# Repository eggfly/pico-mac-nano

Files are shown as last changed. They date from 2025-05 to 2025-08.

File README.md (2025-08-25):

# pico-mac-nano

pico-mac-nano
pico-mac-nanobig brotherinside

v0.3 20 May 2025

Fork of https://github.com/evansm7/pico-mac v0.21

The purpose of this fork is the creation of a miniature functioning Macintosh running pico-mac on a [Waveshare Pico Zero](https://www.waveshare.com/wiki/RP2040-Zero) (or pin/function compatible RP2040 MCU) by adding support for output to a small TFT LCD panel. 

This involved the following steps:
   * Selecting and testing the smallest suitably high resolution display I could locate at
     a reasonable price.
   * Working backwards from the LCD image size to calculate scale of the Macintosh model.
   * Designing the internal layout of the Macintosh to accomodate all components.
   * 3D modelling the Macintosh case in two halves with internal supports for components
   * Designing a PCB to connect all components.
   * Updating the pico-mac source code to ...
   	 - configure the LCD via SPI interface shared with SD card module
   	 - output suitable 480x342 pixel frame buffer data for the LCD
   	 - use the Pico Zero's built in Neo-pixel RGB LED
   	 - output out of phase 600Hz square waves on two GPIOs for 1s at startup to simulate
   	  the Macintosh startup beep

The finished Macintosh is just 62mm high but houses a 2.0" TFT LCD panel, rp2040 Pico Zero MCU, micro-SD card reader and the custom PCB.

For more details on the journey and design decisions, see the [pico-mac-nano project page](https://blog.1bitrainbow.com/pico-mac-nano/).

The firmware directory contains an example, pre-built .uf2 rp2040 firmware file for the Pico Zero. This version is built with the standard 128K ram.

The PCB directory contains all gerber, drill hole, position and BOM files for the most recent revision of the PCB.

Data sheets for the TFT module and the controller are in the data_sheets directory.

The 3D_model directory contains the .stl files for the four components of the Macintosh 128K case; front housing, rear housing, switch blank (blocks the switch apperture intended for the [battery power module](https://www.1bitrainbow.com/parts-store.php?cPath=972_973_P4470)) and reset/boot select button actuator.

All parts used in pico-mac-nano can be ordered on [1bitrainbow.com](https://www.1bitrainbow.com/parts-store.php?cPath=972_973). This includes the 3D printed case, the fully assembled custom PCB and the Pico Zero (pre-flashed with the latest pico-mac-nano firmware). You can even order a fully assembled pico-mac-nano or the collectors edition so you can be as hands-on or hands-off as you want.

## Hardware Notes

The pico code, PCB and Macintosh case are all designed for the 2.0" 480x640px DX7 D200N2409V0 LCD panel. This uses the ST7701S controller, is configured via SPI and receives image data in RGB565 (16-bit colour). This LCD is natively portrait and the ST7701S controller does not offer image rotation in hardware so I am displaying a 480x342 image across the upper half of the LCD panel. See the [pico-mac-nano project page](https://blog.1bitrainbow.com/pico-mac-nano/) for more details of how I got to this decision.

The case and internal layout is designed to allow the Pico Zero and SD module to be connected via 2.54mm header sockets rather than being soldered. Due to the small size of the PCB, I chose not to include sockets for the unused Pico Zero pins. Not having these unnecessary through-hole pins allowed routing of traces more efficiently. Consequently, the Pico Zero connects to the PCB via a 9-pin (J3), a 2-pin (J4), and a 4-pin (J6) socket.

The PCB includes the capacitors (C1 & C2) recommended by evansm7 across the micro-SD card module power rails.

The Pico 5V (VCC) is used to power the TFT backlight via a resistor (R1) which maintains the correct forward voltage specified by the TFT data sheet.

The 40-pin, vertical FFC socket (J1) is used to connect the TFT LCD panel. Note that for some reason, the LCD flex cable has its 'pin' numbers labelled in the reverse order to the FCC socket. This is why the PCB indicates where the LCD flex pin 1 should be.

Labelled test pads are provided on the PCB for all data signals.

Provision for battery power is provided on the PCB in the form of +5v and Ground header pins. This 5v input passes through an on-board Schottky diode (D1) to protect against pico-mac-nano being connected to a USB host and receiving 5V via USB while using battery power.
The optional battery power module which uses a 3v lithium C2 battery, 5v boost regulator and micro switch, is available now on [1bitrainbow.com](https://www.1bitrainbow.com/parts-store.php?cPath=972_973_P4470).

All components should be mounted on the underside of the PCB with the exception of the 2-pin 2.54mm male header (right-angle if using the [1-bit rainbow battery power module](https://www.1bitrainbow.com/parts-store.php?cPath=972_973_P4470)) for 5v battery power, and the 2-pin 2.54mm female header for Audio (Beep). These should be mounted on the top to allow connection of a power source and/or speaker.

pcb bottom
pcb top side

For reference, here are the pin assignments I have used for the Pico Zero.

|**Pin**|Ref|**Function**|
| --- | --- | --- |
|1		|5V			|VCC (TFT Backlight)|
|2		|GND		|Ground|
|3		|3V3		|VDD|
|4		|GPIO 29	|H-Sync|
|5		|GPIO 28	|Pix Clk|
|6		|GPIO 27	|V-Sync|
|7		|GPIO 26	|Vid Data|
|8		|GPIO 15	|TFT Reset|
|9		|GPIO 14	|TFT SPI CS|
|10		|GPIO 13	|Audio +|
|11		|GPIO 12	|Audio -|
|12		|GPIO 11	|N/C|
|13		|GPIO 10	|N/C|
|14		|GPIO 9		|N/C|
|15		|GPIO 8		|N/C|
|16		|GPIO 7		|N/C|
|17		|GPIO 6		|N/C|
|18		|GPIO 5		|SD SPI CS|
|19		|GPIO 4		|SPI MISO (shared)|
|20		|GPIO 3		|SPI MOSI (shared)|
|21		|GPIO 2		|SPI Clk (shared)|
|22		|GPIO 1		|N/C|
|23		|GPIO 0		|N/C|

The Audio + and Audio - pins output a 600Hz square wave for 1 second at the start of the initialisation code to give an approximate rendition of the original Macintosh startup beep. Audio - is just the inverse of (180 deg out of sync with) Audio +. By connecting a speaker between this pair of outputs, we get a 6.6v differential signal which gave an acceptable volume without the need for any amplification. When the speaker was just connected between one output and ground, the volume was too low to be of use (In case you're worrying, both pins are set low after the beep so the Pico is not left with a high GPIO shorting to ground through the speaker).
Audio + and Audio - are presented on their own header pins on the PCB to allow a speaker to be easily connected.
Using a suitable inductor (the value will depend on the impedance of the speaker you are using) in series with the speaker, or a capacitor across the speaker, should filter out some of the higher frequencies so the beep is less buzzy.

As with the pico-mac project, pico-mac-nano is a personal hobby project and proof of concept rather than a commercial product. My aim was to see how small I could make it and this involved some compromises.

Disclaimer: This project is provided with no warranty. All due care has been taken in design/docs, but if you choose to build it then I disclaim any responsibility for your hardware or personal safety.

Below is a modified version of [evansm7](https://github.com/evansm7) original readme from pico-mac v0.21 minus the Hardware Construction section since this variant uses a custom PCB so there is none of the original construction to be done.

# Pico Micro Mac (pico-umac) v0.2
This project embeds the [umac Mac 128K
emulator](https://github.com/evansm7/umac) project into a Raspberry Pi
Pico microcontroller.  At long last, the worst Macintosh in a cheap,
portable form factor!

It has features, many features, the best features:

   * Outputs 480x342px at 60Hz, monochrome to 2.0" LCD 
   * USB HID keyboard and mouse
   * Read-only disc image in flash (your creations are ephemeral, like life itself)
   * Or, if you have a hard time letting go, support for rewritable
     disc storage on an SPI-attached SD card
   * Mac 128K by default, or you can make use of more of the Pico's
     memory and run as a _Mac 208K_

Great features.  It even doesn't hang at random!  (Anymore.)

The _Mac 208K_ was, of course, never a real machine.  But, _umac_
supports odd-sized memories, and more memory runs more things.  A
surprising amount of software runs on the 128K config, but if you need
to run _MacPaint_ specifically then you'll need to build both SD
storage in addition to the _Mac 208K_ config.

To build this project yourself, you'll need at least a WaveShare Pico Zero or compatible board, a 3D printer, the 2.0" LCD panel, SPI micro-SD card module, interconnect PCB, USB mouse (and maybe a USB keyboard/hub), plus a suitable OTG USB splitter.

# Build

## Prerequisites/essentials

   * git submodules
      - Clone the repo with `--recursive`, or `git submodule update --init --recursive`
   * Install/set up the [Pico/RP2040 SDK](https://github.com/raspberrypi/pico-sdk)

## Build umac

Install and build `umac` first using the display width and height options. 
It'll give you a preview of the fun to come, plus is required to generate a patched ROM image.

```
cd external/umac
make DISP_WIDTH=480 DISP_HEIGHT=342
```

If you want to use a non-default memory size (i.e. >128K) you will
need to build `umac` with a matching `MEMSIZE` build parameter, for
example:

```
cd external/umac
make DISP_WIDTH=480 DISP_HEIGHT=342 MEMSIZE=208
```

This is because `umac` is used to patch the ROM, and when using
unsupported sizes between 128K and 512K the RAM size can't be probed
automatically, so the size needs to be embedded.

## Build pico-umac

Do the initial Pico SDK `cmake` setup into an out-of-tree build dir,
providing config options if required.

From the top-level `pico-umac` directory:

```
mkdir build
(cd build ; PICO_SDK_PATH=/path/to/sdk cmake .. <options>)
```

If you want more than the default 128K of memory, you need to build with the following option.
 
   * `-DMEMSIZE=<size in KB>`: The maximum practical size is about
     208KB, but values between 128 and 208 should work on a RP2040.
     Note that although apps and Mac OS seem to gracefully detect free
     memory, these products never existed and some apps might behave
     strangely.
      - With the `Mac Plus` ROM, a _Mac 128K_ doesn't quite have
        enough memory to run _MacPaint_.  So, 192 or 208 (and a
        writeable boot volume on SD) will allow _MacPaint_ to run.
      - **NOTE**: When this option is used, the ROM image must be
          built with an `umac` build with a corresponding `MEMSIZE`

**NOTE** All other options available in pico-mac are still recognised but are not listed here because the LCD and custom PCB used in pico-mac-nano require them to be set to specific values. Overriding the default for any option other than DMEMSIZE will cause problems.

Tip: `cmake` caches these variables, so if you see weird behaviour
having built previously and then changed an option, delete the `build`
directory and start again.

## ROM image

The flow is to use `umac` built on your workstation (e.g. Linux,
but WSL may work too) to prepare a patched ROM image.

`umac` is passed the 4D1F8172 MacPlusv3 ROM, and `-W` to write the
post-patching binary out:

```
./external/umac/main -r '4D1F8172 - MacPlus v3.ROM' -W rom.bin
```

Note: Again, remember that if you are using the `-DMEMSIZE` option to
increase the `pico-umac` memory, you will need to create this ROM
image with a `umac` built with the corresponding `MEMSIZE` option, as
above.

## Disc image

Micro-SD support is enabled by default. An internal read-only disc image is
still stored in flash by default which is used as a fallback if
no SD card is present, no valid boot image exists on the SD card, or the SD boot fails.

Grab a Macintosh system disc from somewhere.  A 400K or 800K floppy
image works just fine, up to System 3.2 (the last version to support
Mac128Ks).  I've used images from
<https://winworldpc.com/product/mac-os-0-6/system-3x> but also check
the various forums and MacintoshRepository.  See the `umac` README for
info on formats (it needs to be raw data without header).

The image size can be whatever you have space for in flash (typically
about 1.3MB is free there), or on the SD card.  (I don't know what the
HFS limits are.  But if you make a 50MB disc you're unlikely to fill
it with software that actually works on the _Mac 128K_ :) )

Use a FAT-formatted micro-SD card and copy your disc image
into _one_ of the following files in the root of the card:

   * `umac0.img`:  A normal read/write disc image
   * `umac0ro.img`:  A read-only disc image

## Putting it together, and building

Given the `rom.bin` prepared above and a `disc.bin` destinated for
flash, you can now generate includes from them and perform the build:

```
mkdir incbin
xxd -i < rom.bin > incbin/umac-rom.h
xxd -i < disc.bin > incbin/umac-disc.h
make -C build
```

You'll get a `build/firmware.uf2` out the other end.  Flash this to
your Pico Zero: e.g. plug it into your computer with the Boot Select button held down. This should cause the Pico Zero to appear as a removable volume. Drag and drop the formware file onto the volume. ([evansm7](https://github.com/evansm7) advocated using an SWD probe but due to design constraints, UART serial pins are not routed on the custom PCB)

The RGB LED should light up blue while the audio beep is being played, rapidly flash red while the LCD is being configured and then steadily flash green at about 2Hz.

# Software

Both CPU cores are used, and are overclocked (blush) to 250MHz so that
Missile Command is enjoyable to play.

The `umac` emulator and video output runs on core 1, and core 0 deals
with USB HID input.  Video DMA is initialised pointing to the
framebuffer in the Mac's RAM.

Other than that, it's just a main loop in `main.c` shuffling things
into `umac`.

Quite a lot of optimisation has been done in `umac` and `Musashi` to
get performance up on Cortex-M0+ and the RP2040, like careful location
of certain routines in RAM, ensuring inlining/constants can be
foldeed, etc.  It's 5x faster than it was at the beginning.

The top-level project might be a useful framework for other emulators,
or other projects that need USB HID input and a framebuffer (e.g. a
VT220 emulator!).

The USB HID code is largely stolen from the TinyUSB example, but shows
how in practice you might capture keypresses/deal with mouse events.

## Video

The video system is pretty good and IMHO worth stealing for other
projects: It uses one PIO state machine and 3 DMA channels to provide
a rock-solid bitmapped 1BPP 480x342 video output. ~~The Mac 512x342
framebuffer is centred inside this by using horizontal blanking
regions (programmed into the line scan-out) and vertical blanking
areas from a dummy "always black" mini-framebuffer.~~

~~It supports (at build time) flexible resolutions/timings.  The one
caveat (or advantage?) is that it uses an HSYNC IRQ routine to
recalculate the next DMA buffer pointer; doing this at scan-time costs
about 1% of the CPU time (on core 1).  However, it could be used to
generate video on-the-fly from characters/tiles without a true
framebuffer.~~

I'm considering improvements to the video system:

   * Supporting multiple BPP/colour output
   * Implement the rest of `DE`/display valid strobe support, making
     driving LCDs possible.
   * Using a video DMA address list and another DMA channel to reduce
     the IRQ frequency (CPU overhead) to per-frame, at the cost of a
     couple of KB of RAM.

# Licence

`hid.c` and `tusb_config.h` are based on code from the TinyUSB
project, which is Copyright (c) 2019, 2021 Ha Thach (tinyusb.org) and
released under the MIT licence.  `sd_hw_config.c` is based on code
from the no-OS-FatFS-SD-SPI-RPi-Pico project, which is Copyright (c)
2021 Carl John Kugler III.

The remainder of the code is released under the MIT licence:

 Copyright (c) 2024 Matt Evans:

 Permission is hereby granted, free of charge, to any person obtaining a copy
 of this software and associated documentation files (the "Software"), to deal
 in the Software without restriction, including without limitation the rights
 to use, copy, modify, merge, publish, distribute, sublicense, and/or sell
 copies of the Software, and to permit persons to whom the Software is
 furnished to do so, subject to the following conditions:

 The above copyright notice and this permission notice shall be included in all
 copies or substantial portions of the Software.

 THE SOFTWARE IS PROVIDED "AS IS", WITHOUT WARRANTY OF ANY KIND, EXPRESS OR
 IMPLIED, INCLUDING BUT NOT LIMITED TO THE WARRANTIES OF MERCHANTABILITY,
 FITNESS FOR A PARTICULAR PURPOSE AND NONINFRINGEMENT. IN NO EVENT SHALL THE
 AUTHORS OR COPYRIGHT HOLDERS BE LIABLE FOR ANY CLAIM, DAMAGES OR OTHER
 LIABILITY, WHETHER IN AN ACTION OF CONTRACT, TORT OR OTHERWISE, ARISING FROM,
 OUT OF OR IN CONNECTION WITH THE SOFTWARE OR THE USE OR OTHER DEALINGS IN THE
 SOFTWARE.

# 关于 208K 和 480 分辨率的编译步骤

* 首先必须 external/umac 带 `make MEMSIZE=208` 然后 ./main -W 从 4D1F8172 - MacPlus v3.ROM 生成 patched_rom
* 然后 pico-mac 项目 cmake的时候 带上-DMEMSIZE=208 (256是不够的，RAM段恰好差了40多KB)
* 生成的width 应该是512的（后续可以通过鼠标滚动处理？）
* 208K可以通过Finder的白色背景的about固件看到
* MacPaint 需要208K 且需要tf卡可读写 disc 模式才能运行，否则弹窗报错

* 另，尝试使用`make DISP_WIDTH=480 DISP_HEIGHT=342 MEMSIZE=208` 打patched_rom以后，再到cmake 出来画面是错位的，然后需要在video.c 中修改#define VIDEO_FB_HRES           480 才可以，不知道为何
* 从128K切换到208K以后，开机速度很慢，且流畅度确实有所降低
* 改成480以后，左边出现了32像素的黑色边，右边超出屏幕了，video.c中还没有找到合适的改法
* external/umac 会有.o 目标文件，在外面make的时候可能会用到缓存，所以在重新配置MEMSIZE等参数的时候，需要make clean一下umac

# 128K 内存可以运行程序列表:
* Alice 国际象棋
* Aliens 小蜜蜂
* Amazing 迷宫但是需要512宽度
* MacLanding
* Bricks 打砖块
* ChipWits 黑屏
* City Defense
* Crystal Radar
* Daleks 逃脱游戏
* Destroyer
* Frogger 崩溃了
* Fusillade
* GATO 不行
* GridWars OK 3D效果不错
* GroundZero OK
* Hearts OK
* Life OK
* Missle Command OK
* MLScores OK
* Mouse
* Reversi ok
* Sargon III OK 国际象棋
* Solitaire 1.0 OK
* Transylvania 企鹅游戏不会玩
* 汉诺塔 OK

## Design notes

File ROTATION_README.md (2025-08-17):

# 屏幕旋转功能说明

## 概述

这个项目为RP2040给ST7701S刷屏的代码添加了软件屏幕旋转功能。由于ST7701S硬件不支持旋转，我们通过软件方式实现了90度、180度和270度的屏幕旋转。

## 功能特性

- **90度顺时针旋转**: 将512×342的Macintosh画面旋转90度
- **270度顺时针旋转**: 将512×342的Macintosh画面旋转270度（等同于90度逆时针）
- **180度旋转**: 将512×342的Macintosh画面旋转180度
- **实时更新**: 在每次vsync时自动更新旋转缓冲区

## 实现原理

### 坐标映射
- **90度旋转**: `(x, y) → (y, 511-x)`
- **180度旋转**: `(x, y) → (511-x, 341-y)`
- **270度旋转**: `(x, y) → (341-y, x)`

### 缓冲区管理
- 对于90度和270度旋转，使用额外的旋转缓冲区（342×512）
- 对于0度和180度旋转，直接使用原始缓冲区
- 在每次vsync时更新旋转缓冲区

## 使用方法

### 1. 启用旋转功能

在`src/main.c`的`core1_main()`函数中，取消注释相应的旋转设置：

```c
// 启用90度顺时针旋转
video_set_rotation(ROTATION_90);

// 启用270度顺时针旋转（90度逆时针）
video_set_rotation(ROTATION_270);

// 启用180度旋转
video_set_rotation(ROTATION_180);

// 禁用旋转（正常显示）
video_set_rotation(ROTATION_0);
```

### 2. 编译和烧录

```bash
mkdir build
cd build
cmake ..
make
```

将生成的`firmware.uf2`文件烧录到RP2040设备。

## 性能考虑

### 内存使用
- 90/270度旋转需要额外的旋转缓冲区：342×512÷8 = 21,888字节
- 180度旋转不需要额外缓冲区

### CPU开销
- 90/270度旋转：每次vsync需要重新计算整个帧缓冲区
- 180度旋转：相对较低的开销
- 0度旋转：无额外开销

### 建议
- 如果内存紧张，建议使用180度旋转
- 如果需要90/270度旋转，确保有足够的RAM

## 技术细节

### 位操作优化
旋转算法针对1BPP（每像素1位）格式进行了优化：
- 使用位操作而不是字节操作
- 支持MSB优先的位序
- 高效的坐标映射

### DMA配置
- 自动调整DMA传输大小以适应旋转后的分辨率
- 保持与PIO视频输出的兼容性

## 故障排除

### 常见问题

1. **内存不足**
   - 错误信息：`Failed to allocate rotated framebuffer`
   - 解决方案：减少其他内存使用或使用180度旋转

2. **显示异常**
   - 检查旋转模式设置是否正确
   - 确认vsync更新是否正常工作

3. **性能问题**
   - 考虑降低系统时钟频率
   - 优化其他后台任务

## 扩展功能

### 动态旋转切换
可以通过按键或其他输入方式动态切换旋转模式：

```c
// 示例：按键切换旋转模式
if (key_pressed) {
    static rotation_mode_t current = ROTATION_0;
    current = (current + 1) % 4; // 循环切换
    video_set_rotation(current);
}
```

### 自定义旋转角度
当前实现支持90度的倍数旋转。如果需要其他角度，需要修改坐标映射函数。

## 许可证

本功能遵循与原项目相同的MIT许可证。

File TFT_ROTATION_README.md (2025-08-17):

# ST7701S TFT屏幕软件旋转实现

## 概述

由于ST7701S TFT控制器不支持硬件旋转功能，我们实现了软件旋转来将竖屏显示（480x640）转换为横屏显示（640x480）。

## 实现原理

### 1. 显示系统架构

这个项目使用的是 **PIO + RGB并行接口** 的显示系统：

```
Mac帧缓冲区 → DMA → PIO程序 → RGB时序信号 → TFT屏幕
```

- **PIO程序** (`pio_video.pio`) 生成 HSync、VSync、Pixel Clock 时序
- **DMA** 从帧缓冲区读取像素数据
- **RGB并行接口** 直接输出到TFT屏幕

### 2. 软件旋转算法

在帧缓冲区层面实现90度顺时针旋转：

```c
// 原始坐标 (x, y) -> 旋转后坐标 (dst_x, dst_y)
dst_x = src_height - 1 - y;  // 旋转后的x坐标
dst_y = x;                   // 旋转后的y坐标
```

### 3. 显示参数调整

- **原始配置**：480x640（竖屏）
- **旋转后配置**：640x480（横屏）
- **帧缓冲区**：512x342（Mac原始分辨率）

### 4. 关键修改

#### 视频处理 (`src/video.c`)
- 添加了软件旋转函数 `video_rotate_framebuffer()`
- 修改了 `video_line_addr()` 函数使用旋转后的缓冲区
- 在DMA中断中每帧重新计算旋转

#### 视频配置
- 保持原始分辨率：`VIDEO_HRES = 480`, `VIDEO_VRES = 640`
- 在数据层面进行旋转，而不是改变时序

## 使用方法

### 1. 启用软件旋转

在 `src/tft_2p.c` 中设置：
```c
#define TFT_ROTATION_ENABLED 1  // 启用软件旋转
```

### 2. 调用旋转显示函数

```c
// 显示旋转后的帧缓冲区
tft_display_rotated(framebuffer, width, height);
```

### 3. 测试程序

运行 `src/tft_test.c` 来测试软件旋转功能。

## 性能考虑

### 内存使用
- 需要额外的旋转缓冲区：`TFT_ROTATED_WIDTH * TFT_ROTATED_HEIGHT / 32`
- 旋转操作需要CPU时间进行像素重排

### 优化建议
1. **DMA传输**：可以考虑使用DMA来加速旋转后的数据传输
2. **缓存优化**：对于静态内容，可以预计算旋转结果
3. **部分更新**：只旋转需要更新的区域

## 兼容性

### 支持的旋转角度
- 目前支持90度顺时针旋转
- 可以扩展支持180度和270度旋转

### 分辨率支持
- 支持任意分辨率的旋转
- 当前配置：512x342 -> 342x512

## 注意事项

1. **内存限制**：旋转缓冲区需要额外的RAM空间
2. **性能影响**：软件旋转会增加CPU负载
3. **实时性**：对于高刷新率应用，需要考虑旋转计算时间

## 未来改进

1. **硬件加速**：如果可能，考虑使用PIO或DMA来加速旋转
2. **多角度支持**：添加180度和270度旋转支持
3. **动态切换**：运行时切换旋转角度
4. **性能优化**：使用查找表或SIMD指令优化旋转算法

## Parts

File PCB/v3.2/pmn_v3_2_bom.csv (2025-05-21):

Comment | Designator | Footprint | Manufacturer | Mfg Part #
1uf Tantalum 16v | C1 | SMD 1206 (3216 metric) | KYOCERA | F931C105KAA
0.1uf MLCC 16v | C2 | SMD 1206 (3216 metric) | YAGEO | CC1206KRX7R7BB104
Schottky Diode 40v 1A | D1 | SMD SOD-123 | ROHM | RB168M150DDTR
FFC2A32-40-T | J1 | SMD 0.5-40PVertical welding | Amphenol Aorora (or GCT) | F314-1A7H1-11040 (FFC2A32-40-G)
22ohms 250mW | R1 | SMD 1206 (3216 metric) | YAGEO | RT1206FRE0722RL

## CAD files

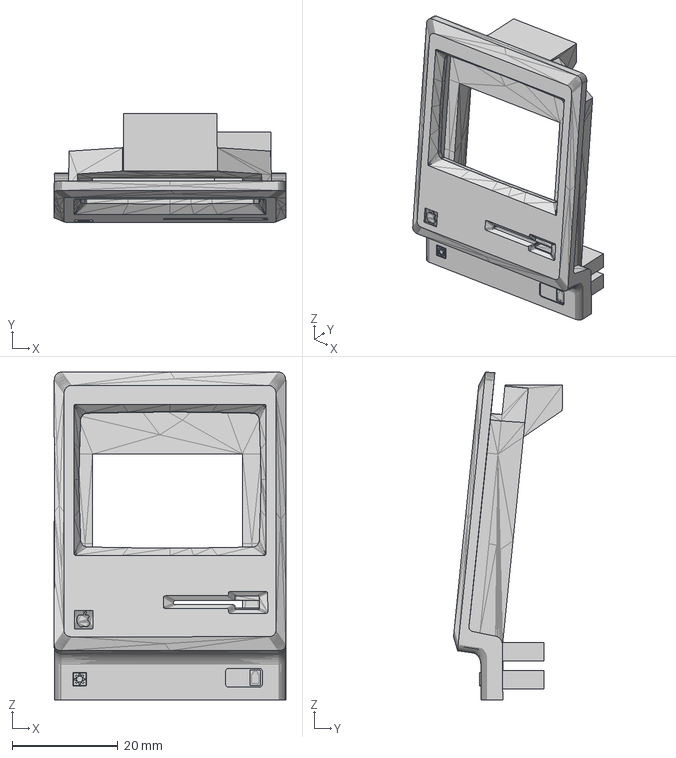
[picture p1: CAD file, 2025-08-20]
3D_model/not_fixed/uPicoMac v18-front.step
43.8 x 20.6 x 62.0 mm

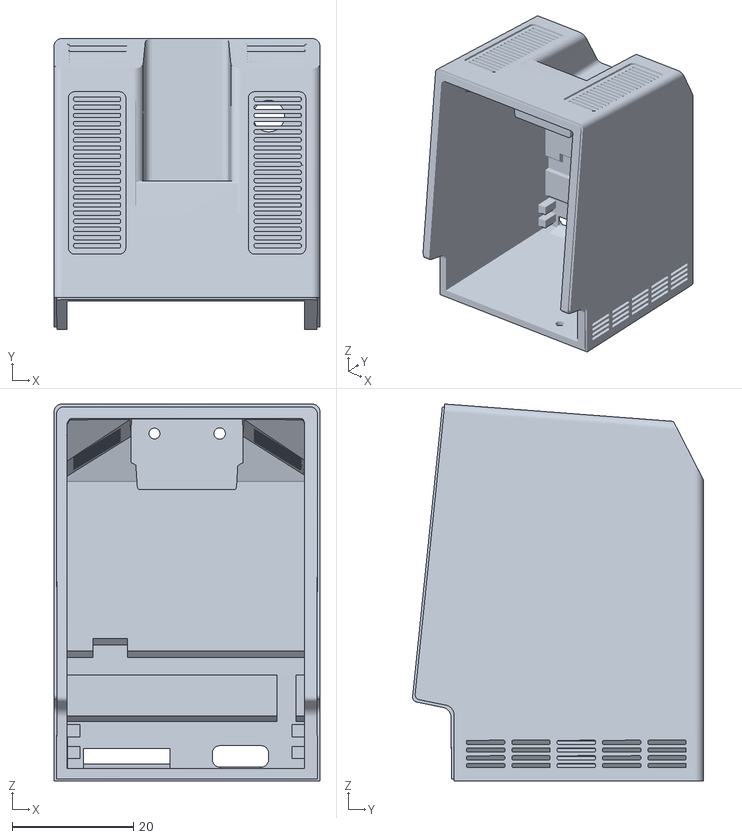
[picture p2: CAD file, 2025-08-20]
3D_model/uPicoMac v18-rear_fixed.stl
43.8 x 47.9 x 62.1

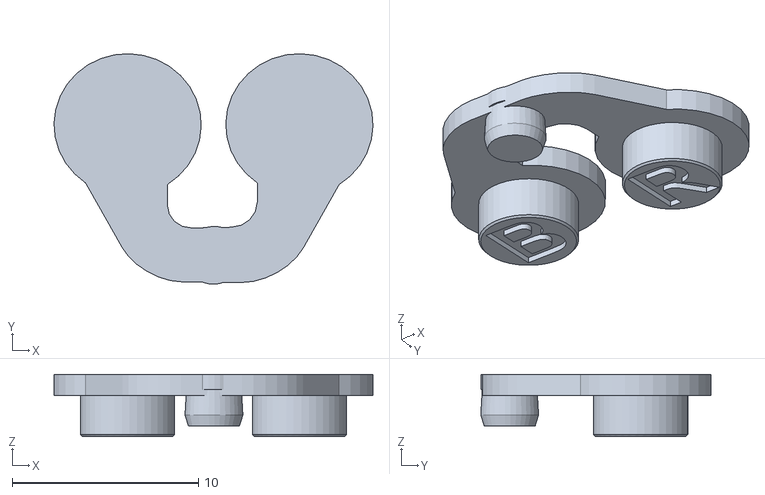
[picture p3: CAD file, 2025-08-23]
3D_model/uPicoMacTypeA_v5/uPicoMacTypeA v5-button_fixed.stl
17.1 x 12.4 x 3.34

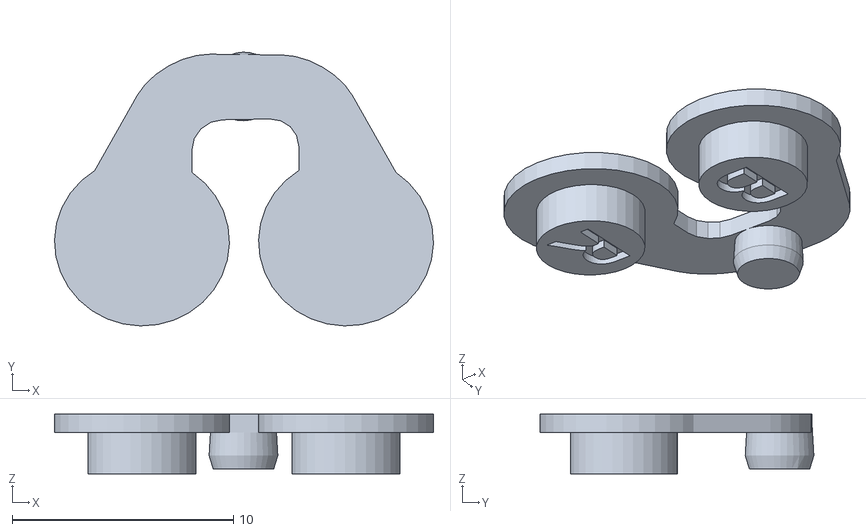
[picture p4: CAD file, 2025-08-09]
3D_model/v3/3d_mac/pmn_reset_3_2_fixed.stl
17.1 x 12.4 x 2.70

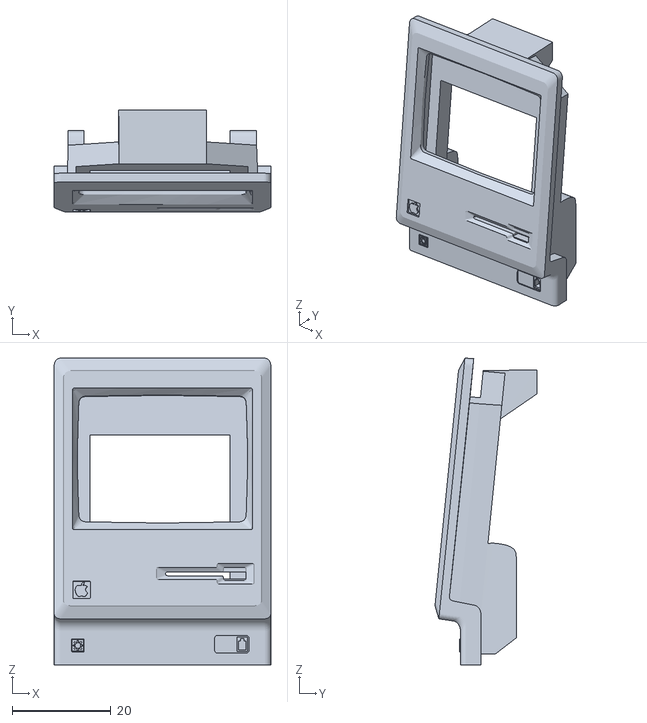
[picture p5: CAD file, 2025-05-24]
3D_model/v3/pmn_front_3_3.stl
43.8 x 20.6 x 62.0

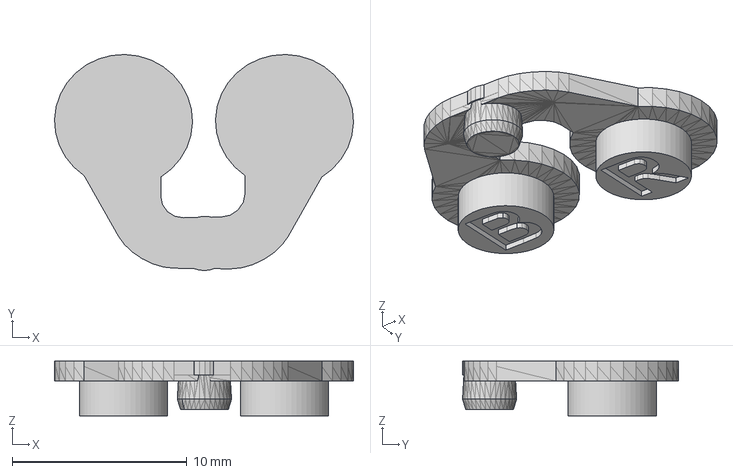
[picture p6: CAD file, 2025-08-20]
3D_model/not_fixed/uPicoMac v18-button.step
17.1 x 12.4 x 3.14 mm

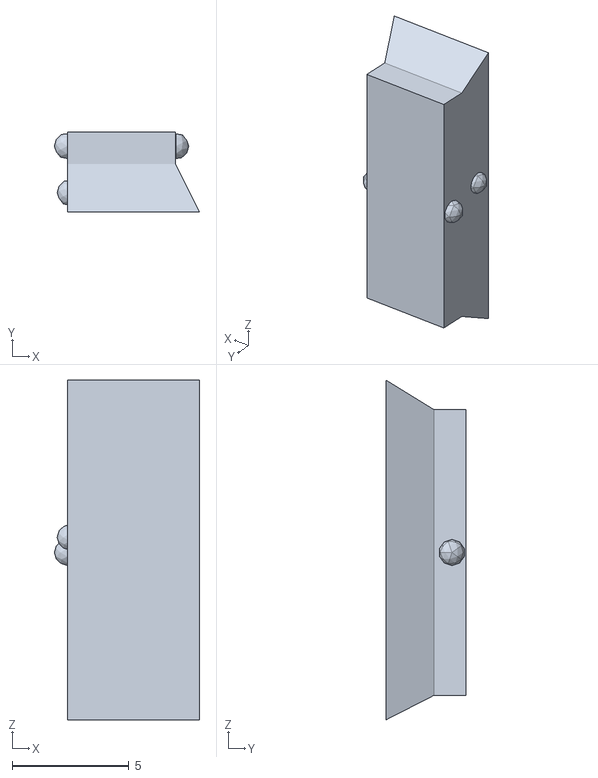
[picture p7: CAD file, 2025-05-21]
3D_model/v3/pmn_switch_blank_3_2.stl
6.22 x 3.44 x 14.5

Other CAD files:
3D_model/uPicoMac v19-front_extended_0.2mm_fixed.stl
3D_model/uPicoMacTypeA_v5/uPicoMacTypeA v5-rear_fixed.stl
3D_model/v3/3d_mac/pmn_rear_3_3_fixed_mixer_fixed.stl
3D_model/v3/pmn_rear_3_3.stl
3D_model/uPicoMac v18-button_fixed.stl
3D_model/uPicoMacTypeA_v5/uPicoMacTypeA v5-front_fixed.stl
3D_model/v3/3d_mac/pmn_front_3_3_fixed.stl
3D_model/v3/3d_mac/pmn_switch_blank_3_2_fixed.stl
3D_model/v3/pmn_reset_3_2.stl
3D_model/old/uPicoMac v16 button_fixed.stl
3D_model/old/uPicoMac v18-front_fixed.stl
3D_model/old/uPicoMac v16 front_fixed.stl

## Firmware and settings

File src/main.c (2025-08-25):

/* pico-umac
 *
 * Main loop to initialise umac, and run main event loop (piping
 * keyboard/mouse events in).
 *
 * Copyright 2024 Matt Evans
 *
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
 * THE SOFTWARE IS PROVIDED "AS IS", WITHOUT WARRANTY OF ANY KIND,
 * EXPRESS OR IMPLIED, INCLUDING BUT NOT LIMITED TO THE WARRANTIES OF
 * MERCHANTABILITY, FITNESS FOR A PARTICULAR PURPOSE AND
 * NONINFRINGEMENT. IN NO EVENT SHALL THE AUTHORS OR COPYRIGHT HOLDERS
 * BE LIABLE FOR ANY CLAIM, DAMAGES OR OTHER LIABILITY, WHETHER IN AN
 * ACTION OF CONTRACT, TORT OR OTHERWISE, ARISING FROM, OUT OF OR IN
 * CONNECTION WITH THE SOFTWARE OR THE USE OR OTHER DEALINGS IN THE
 * SOFTWARE.
 */

#include <stdio.h>
#include <unistd.h>
#include <string.h>
#include "hardware/clocks.h"
#include "hardware/gpio.h"
#include "hardware/pio.h"
#include "hardware/sync.h"
#include "hardware/pwm.h"
#include "pico/multicore.h"
#include "pico/stdlib.h"
#include "pico/time.h"
#include "hw.h"
#include "video.h"
#include "kbd.h"

#include "bsp/rp2040/board.h"
#include "tusb.h"

#include "umac.h"

#if USE_SD
#include "f_util.h"
#include "ff.h"
#include "rtc.h"
#include "hw_config.h"
#endif

#if PICO_ZERO
#include "ws2812.h"
#include "ws2812.pio.h"
#endif

#if TFT_2P
#include "tft_2p.h"
#endif

#if BEEP
#include "audio.h"
#endif

extern hid_info_t g_hid_info;

////////////////////////////////////////////////////////////////////////////////
// Imports and data

extern void     hid_app_task(void);
extern int cursor_x;
extern int cursor_y;
extern int cursor_button;

// Mac binary data:  disc and ROM images
static const uint8_t umac_disc[] = {
#include "umac-disc.h"
};
static const uint8_t umac_rom[] = {
#include "umac-rom.h"
};

static uint8_t umac_ram[RAM_SIZE];

////////////////////////////////////////////////////////////////////////////////

// PWM初始化函数
static void init_pwm_outputs()
{
        // IO6 PWM配置
        gpio_set_function(6, GPIO_FUNC_PWM);
        uint slice_num_6 = pwm_gpio_to_slice_num(6);
        uint chan_6 = pwm_gpio_to_channel(6);
        
        // 设置PWM频率为1kHz
        pwm_set_clkdiv(slice_num_6, 125.0f); // 125MHz / 125 = 1MHz
        pwm_set_wrap(slice_num_6, 9999); // 1MHz / 10000 = 100Hz，但可以设置更低占空比
        pwm_set_chan_level(slice_num_6, chan_6, 9999); // 0.01%占空比 (1/10000)
        pwm_set_enabled(slice_num_6, true);
        
        printf("IO6 PWM initialized: 100Hz, 0.01%% duty cycle\n");
        
        // IO7 PWM配置检查
        gpio_set_function(7, GPIO_FUNC_PWM);
        uint slice_num_7 = pwm_gpio_to_slice_num(7);
        uint chan_7 = pwm_gpio_to_channel(7);
        
        // 检查IO7是否可以配置为PWM
        if (slice_num_7 != slice_num_6) {
                // IO7使用不同的PWM slice，可以独立配置
                pwm_set_clkdiv(slice_num_7, 125.0f);
                pwm_set_wrap(slice_num_7, 999);
                pwm_set_chan_level(slice_num_7, chan_7, 250); // 25%占空比作为测试
                pwm_set_enabled(slice_num_7, true);
                printf("IO7 PWM initialized: 1kHz, 25%% duty cycle\n");
        } else {
                // IO7与IO6共享同一个PWM slice，只能使用相同的频率
                pwm_set_chan_level(slice_num_7, chan_7, 750); // 75%占空比
                pwm_set_enabled(slice_num_7, true);
                printf("IO7 PWM initialized: same frequency as IO6, 75%% duty cycle\n");
        }
}

static void     io_init()
{
#if PICO_ZERO
                PIO pio = pio1; /* Use PIO 1 as Vidio is using PIO 0 */
                uint offset = pio_add_program(pio, &ws2812_program);
                uint sm = pio_claim_unused_sm(pio, true); //Claim a free state machine on a PIO instance
                ws2812_program_init(pio, sm, offset, GPIO_LED_PIN, 800000, true); /* 800000 is frequency */
#else
                gpio_init(GPIO_LED_PIN);
                gpio_set_dir(GPIO_LED_PIN, GPIO_OUT);
#endif
}

static void     poll_led_etc()
{
        static uint8_t led_on = 0;
        static absolute_time_t last = 0;
        absolute_time_t now = get_absolute_time();
        bool hasKeyboard = false;
        bool hasMouse = false;
        for (int i = 0; i < CFG_TUH_HID; i++) {
                if (g_hid_info.info[i].hid_type == 1) {
                        if (!hasKeyboard) {
                            hasKeyboard = true;
                        }       
                } else if (g_hid_info.info[i].hid_type == 2) {
                        if (!hasMouse) {
                            hasMouse = true;
                        }
                }
        }
        // Mouse exist led color green, keyboard exist led color blue
        uint8_t red = 0;
        uint8_t green = 0;
        uint8_t blue = 0;
        // red -> green
        // blue -> blue
        // green -> red
        if (hasMouse && !hasKeyboard) {
                green = 1;
        }else if (hasKeyboard && !hasMouse) {
                red = 1;
        }else if (hasKeyboard && hasMouse) {
                red = 1;
                green = 1;
                blue = 1;
        } else {
                // all 0
        }
        if (absolute_time_diff_us(last, now) > 500*1000) {
                last = now;
                printf("hasKeyboard = %d, hasMouse = %d, red = %d, green = %d, blue = %d\r\n", hasKeyboard, hasMouse, red, green, blue);

                led_on ^= 1;
#if PICO_ZERO
                put_pixel_rgb(red, green, blue); 
#else
                gpio_put(GPIO_LED_PIN, led_on);
#endif
        }
}

static int umac_cursor_x = 0;
static int umac_cursor_y = 0;
static int umac_cursor_button = 0;

static void     poll_umac()
{
        static absolute_time_t last_1hz = 0;
        static absolute_time_t last_vsync = 0;
        absolute_time_t now = get_absolute_time();

        umac_loop();

        int64_t p_1hz = absolute_time_diff_us(last_1hz, now);
        int64_t p_vsync = absolute_time_diff_us(last_vsync, now);
        if (p_vsync >= 16667) {
                /* FIXME: Trigger this off actual vsync */
                umac_vsync_event();
                last_vsync = now;
        }
        if (p_1hz >= 1000000) {
                umac_1hz_event();
                last_1hz = now;
        }

        int update = 0;
        int dx = 0;
        int dy = 0;
        int b = umac_cursor_button;
        if (cursor_x != umac_cursor_x) {
                dx = cursor_x - umac_cursor_x;
                umac_cursor_x = cursor_x;
                update = 1;
        }
        if (cursor_y != umac_cursor_y) {
                dy = cursor_y - umac_cursor_y;
                umac_cursor_y = cursor_y;
                update = 1;
        }
        if (cursor_button != umac_cursor_button) {
                b = cursor_button;
                umac_cursor_button = cursor_button;
                update = 1;
        }
        if (update) {
                umac_mouse(dx, -dy, b);
        }
        // handle_my_mouse(cursor_x, cursor_y, cursor_button);

        if (!kbd_queue_empty()) {
                uint16_t k = kbd_queue_pop();
                umac_kbd_event(k & 0xff, !!(k & 0x8000));
        }
}

#if USE_SD
static int      disc_do_read(void *ctx, uint8_t *data, unsigned int offset, unsigned int len)
{
        FIL *fp = (FIL *)ctx;
        f_lseek(fp, offset);
        unsigned int did_read = 0;
        FRESULT fr = f_read(fp, data, len, &did_read);
        if (fr != FR_OK || len != did_read) {
                printf("disc: f_read returned %d, read %u (of %u)\n", fr, did_read, len);
                return -1;
        }
        return 0;
}

static int      disc_do_write(void *ctx, uint8_t *data, unsigned int offset, unsigned int len)
{
        FIL *fp = (FIL *)ctx;
        f_lseek(fp, offset);
        unsigned int did_write = 0;
        FRESULT fr = f_write(fp, data, len, &did_write);
        if (fr != FR_OK || len != did_write) {
                printf("disc: f_write returned %d, read %u (of %u)\n", fr, did_write, len);
                return -1;
        }
        return 0;
}

static FIL discfp;
#endif

static void     disc_setup(disc_descr_t discs[DISC_NUM_DRIVES])
{
#if USE_SD
        char *disc0_name;
        const char *disc0_ro_name = "umac0ro.img";
        const char *disc0_pattern = "umac0*.img";

        /* Mount SD filesystem */
        printf("Starting SPI/FatFS:\n");
        set_spi_dma_irq_channel(true, false);
        sd_card_t *pSD = sd_get_by_num(0);
        FRESULT fr = f_mount(&pSD->fatfs, pSD->pcName, 1);
        printf("  mount: %d\n", fr);
        if (fr != FR_OK) {
                printf("  error mounting disc: %s (%d)\n", FRESULT_str(fr), fr);
                goto no_sd;
        }

        /* Look for a disc image */
        DIR di = {0};
        FILINFO fi = {0};
        fr = f_findfirst(&di, &fi, "/", disc0_pattern);
        if (fr != FR_OK) {
                printf("  Can't find images %s: %s (%d)\n", disc0_pattern, FRESULT_str(fr), fr);
                goto no_sd;
        }
        disc0_name = fi.fname;
        f_closedir(&di);

        int read_only = !strcmp(disc0_name, disc0_ro_name);
        printf("  Opening %s (R%c)\n", disc0_name, read_only ? 'O' : 'W');

        /* Open image, set up disc info: */
        fr = f_open(&discfp, disc0_name, FA_OPEN_EXISTING | FA_READ | FA_WRITE);
        if (fr != FR_OK && fr != FR_EXIST) {
                printf("  *** Can't open %s: %s (%d)!\n", disc0_name, FRESULT_str(fr), fr);
                goto no_sd;
        } else {
                printf("  Opened, size 0x%x\n", f_size(&discfp));
                if (read_only)
                        printf("  (disc is read-only)\n");
                discs[0].base = 0; // Means use R/W ops
                discs[0].read_only = read_only;
                discs[0].size = f_size(&discfp);
                discs[0].op_ctx = &discfp;
                discs[0].op_read = disc_do_read;
                discs[0].op_write = disc_do_write;
        }

        /* FIXME: Other files can be stored on SD too, such as logging
         * and NVRAM storage.
         *
         * We could also implement a menu here to select an image,
         * writing text to the framebuffer and checking kbd_queue_*()
         * for user input.
         */
        return;

no_sd:
#endif
        /* If we don't find (or look for) an SD-based image, attempt
         * to use in-flash disc image:
         */
        discs[0].base = (void *)umac_disc;
        discs[0].read_only = 1;
        discs[0].size = sizeof(umac_disc);
}

static void     core1_main()
{
        disc_descr_t discs[DISC_NUM_DRIVES] = {0};

        printf("Core 1 started\n");
        disc_setup(discs);

        umac_init(umac_ram, (void *)umac_rom, discs);

       /* Video runs on core 1, i.e. IRQs/DMA are unaffected by
         * core 0's USB activity.
         */
        video_init((uint32_t *)(umac_ram + umac_get_fb_offset()));

        printf("Enjoyable Mac times now begin:\n\n");

        while (true) {
                poll_umac();
        }
}

int     main()
{
        set_sys_clock_khz(200*1000, true);

	stdio_init_all();
        io_init(); /* Just sets up the LED */
        
        // 初始化PWM功能
        init_pwm_outputs();

#if BEEP
        printf("Output audio beep\n");
        beep();
#endif

#if TFT_2P /* Need to initialise TFT before UMAC starts because SPI is shared between TFT and SD card */
        printf("TFT init\n");
        tft_init();
#endif

        multicore_launch_core1(core1_main);

	printf("Starting, init usb\n");
        tusb_init();

        /* This happens on core 0: */
	while (true) {
                tuh_task();
                hid_app_task();
                poll_led_etc();
                
                // // Add periodic hub status monitoring
                // static uint32_t last_hub_check = 0;
                // uint32_t now = to_ms_since_boot(get_absolute_time());
                // if (now - last_hub_check > 5000) { // Check every 5 seconds
                //         printf("USB Hub Status Check - Device count: %d\r\n", tuh_device_count());
                //         last_hub_check = now;
                // }
	}

	return 0;
}

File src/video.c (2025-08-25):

/* Video output:
 *
 * NJG: Modified to use 480x342 frame buffer output across top of 480x640 portrait LCD.
 * 
 * Using PIO[1], output the Mac 480x342 1BPP framebuffer to VGA/pins.  This is done
 * directly from the Mac framebuffer (without having to reformat in an intermediate
 * buffer).  The video output is 640x480, with the visible pixel data centred with
 * borders:  for analog VGA this is easy, as it just means increasing the horizontal
 * back porch/front porch (time between syncs and active video) and reducing the
 * display portion of a line.
 *
 * [1]: see pio_video.pio
 *
 * Copyright 2024 Matt Evans
 *
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
 * THE SOFTWARE IS PROVIDED "AS IS", WITHOUT WARRANTY OF ANY KIND,
 * EXPRESS OR IMPLIED, INCLUDING BUT NOT LIMITED TO THE WARRANTIES OF
 * MERCHANTABILITY, FITNESS FOR A PARTICULAR PURPOSE AND
 * NONINFRINGEMENT. IN NO EVENT SHALL THE AUTHORS OR COPYRIGHT HOLDERS
 * BE LIABLE FOR ANY CLAIM, DAMAGES OR OTHER LIABILITY, WHETHER IN AN
 * ACTION OF CONTRACT, TORT OR OTHERWISE, ARISING FROM, OUT OF OR IN
 * CONNECTION WITH THE SOFTWARE OR THE USE OR OTHER DEALINGS IN THE
 * SOFTWARE.
 */

#include <stdio.h>
#include <inttypes.h>
#include <string.h>
#include "pico/time.h"
#include "hardware/clocks.h"
#include "hardware/dma.h"
#include "hardware/gpio.h"
#include "hardware/structs/padsbank0.h"
#include "pio_video.pio.h"

#include "hw.h"
#include "font.h"

#define CUSTOM_TITLE_BAR 0


// 内存监控函数
static void print_memory_usage() {
    
    printf("==================\n");
}
// 1bpp 24x31 image, 1=row major, black=1, white=0
const uint8_t mac_icon[31*3] = {
        0x3f, 0xff, 0xfc,
        0x40, 0x00, 0x02,
        0x80, 0x00, 0x01,
        0x8f, 0xff, 0xf1,
        0x90, 0x00, 0x09,
        0x90, 0x00, 0x09,
        0x90, 0x00, 0x09,
        0x90, 0x89, 0x09,
        0x90, 0x92, 0x09,
        0x90, 0x92, 0x09,
        0x90, 0x00, 0x09,
        0x90, 0x00, 0x09,
        0x90, 0x00, 0x09,
        0x90, 0x00, 0x09,
        0x90, 0x00, 0x09,
        0x90, 0x00, 0x09,
        0x90, 0x00, 0x09,
        0x90, 0x00, 0x09,
        0x90, 0x00, 0x09,
        0x90, 0x00, 0x09,
        0x90, 0x00, 0x09,
        0x90, 0x00, 0x09,
        0x90, 0x00, 0x09,
        0x90, 0x00, 0x09,
        0x90, 0x00, 0x09,
        0x90, 0x00, 0x09,
        0x90, 0x00, 0x09,
        0x90, 0x00, 0x09,
        0x50, 0x00, 0x0a,
        0x4c, 0x00, 0x32,
        0x43, 0xff, 0xc2
    };

// 使用 draw_pixel 函数绘制 mac_icon，通过行列循环保证字节序
void draw_mac_icon(uint32_t *framebuffer, int start_x, int start_y) {
    const int icon_width = 24;
    const int icon_height = 31;
    
    // 遍历图标的每一行
    for (int row = 0; row < icon_height; row++) {
        // 计算当前行在 mac_icon 数组中的起始位置
        int byte_offset = row * 3; // 每行3个字节
        
        // 遍历图标的每一列
        for (int col = 0; col < icon_width; col++) {
            // 计算当前像素在字节中的位置
            int byte_index = col / 8;  // 0, 1, 2
            int bit_index = 7 - (col % 8);  // 从高位到低位，7,6,5,4,3,2,1,0
            
            // 获取对应的字节
            uint8_t pixel_byte = mac_icon[byte_offset + byte_index];
            
            // 提取像素值（1=黑色，0=白色）
            bool is_black = (pixel_byte & (1 << bit_index)) != 0;
            
            // 使用 draw_pixel 函数绘制像素，保证字节序
            draw_pixel(framebuffer, start_x + col, start_y + row, is_black);
        }
    }
}
    
////////////////////////////////////////////////////////////////////////////////
/* VESA VGA mode 640x480@60 */

/* The pixel clock _should_ be (125/2/25.175) (about 2.483) but that seems to
 * make my VGA-HDMI adapter sample weird, and pixels crawl.  Fudge a little,
 * looks better:
 */
#define VIDEO_PCLK_MULT         (4) /* Was (2.5*2) */
#define VIDEO_HSW               2  /* Was 96 */
#define VIDEO_HBP               63  /* Horizontal Back Porch */
#define VIDEO_HRES              480 /* Hor Resolution. changed from 640 */
#define VIDEO_HFP               32  /* Horizontal Front Porch */
#define VIDEO_H_TOTAL_NOSYNC    (VIDEO_HBP + VIDEO_HRES + VIDEO_HFP)
#define VIDEO_VSW               2
#define VIDEO_VBP               17  /* Vertical Back Porch. changed from 33 */
#define VIDEO_VRES              640 /* Ver Resolution. changed from 480 */
#define VIDEO_VFP               12  /* Vertical Front Porch */
#define VIDEO_V_TOTAL           (VIDEO_VSW + VIDEO_VBP + VIDEO_VRES + VIDEO_VFP)
/* The visible vertical span in the VGA output, [start, end) lines: */
#define VIDEO_V_VIS_START       (VIDEO_VSW + VIDEO_VBP)
#define VIDEO_V_VIS_END         (VIDEO_V_VIS_START + VIDEO_VRES)

#define VIDEO_FB_HRES           512 /* changed from 512 */
#define VIDEO_FB_VRES           342

/* The lines at which the FB data is actively output: */
#define VIDEO_FB_V_VIS_START    118      /* Was (VIDEO_V_VIS_START + ((VIDEO_VRES - VIDEO_FB_VRES)/2)) */
#define VIDEO_FB_V_VIS_END      (VIDEO_FB_V_VIS_START + VIDEO_FB_VRES)

/* Words of 1BPP pixel data per line; this dictates the length of the
 * video data DMA transfer:
 */
#define VIDEO_VISIBLE_WPL       (VIDEO_FB_HRES / 32) /* Words per line?? */

#if (VIDEO_HRES & 31)
#error "VIDEO_HRES: must be a multiple of 32b!"
#endif

////////////////////////////////////////////////////////////////////////////////
// Video DMA, framebuffer pointers
// 上面镂空 118, 下面高度180
static uint32_t video_null[VIDEO_VISIBLE_WPL * 207]; // TODO: 这个尺寸不重要，且看是否超过了__HeapLimit

static uint32_t *video_framebuffer;

/* DMA buffer containing 2 pairs of per-line config words, for VS and not-VS: */
static uint32_t video_dma_cfg[4];

/* 3 DMA channels are used.  The first to transfer data to PIO, and
 * the other two to transfer descriptors to the first channel.
 */
static uint8_t video_dmach_tx;
static uint8_t video_dmach_descr_cfg;
static uint8_t video_dmach_descr_data;

typedef struct {
        const void *raddr;
        void *waddr;
        uint32_t count;
        uint32_t ctrl;
} dma_descr_t;

static dma_descr_t video_dmadescr_cfg;
static dma_descr_t video_dmadescr_data;

static volatile unsigned int video_current_y = 0;

static int      __not_in_flash_func(video_get_visible_y)(unsigned int y) {
        if ((y >= VIDEO_FB_V_VIS_START) && (y < VIDEO_FB_V_VIS_END)) {
                return y - VIDEO_FB_V_VIS_START;
        } else {
                return -1;
        }
}

static const uint32_t   *__not_in_flash_func(video_line_addr)(unsigned int y)
{
        int vy = video_get_visible_y(y);
        if (vy >= 0)
                return (const uint32_t *)&video_framebuffer[vy * VIDEO_VISIBLE_WPL];
        else if (y<VIDEO_FB_V_VIS_START) {
                // 减去 27 参数是正确的，减去越大，越靠上
                return (const uint32_t *)&video_null[((signed int)y-27)*VIDEO_VISIBLE_WPL];
        }
        else {
                return (const uint32_t *)&video_null[(y-VIDEO_FB_V_VIS_END)*VIDEO_VISIBLE_WPL];
        }
}

static const uint32_t   *__not_in_flash_func(video_cfg_addr)(unsigned int y)
{
        return &video_dma_cfg[(y < VIDEO_VSW) ? 0 : 2];
}
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

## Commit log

2025-02-23 Update README.md
    Re-named and revised purpose of repo to cover whole project Including 3D modelled case and custom PCB.
2025-04-26 Version 1 PCB and matching code files
    [Macintosh with headers 1 reset.stl, Macintosh with headers front2.stl, Macintosh with headers rear2.stl]
2025-05-06 v3.0 First full project including 3D models and PCB design
    [pmn_front_3_0.stl, pmn_rear_3_0.stl, pmn_reset_3_0.stl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]
2025-05-06 Clean up
    [Macintosh with headers 1 reset.stl, Macintosh with headers front2.stl, Macintosh with headers rear2.stl]
2025-05-21 Version 3.2 of case and PCB with support for battery power module.
    [KiCAD_uPicomac3_2-B_Courtyard.gbr, KiCAD_uPicomac3_2-B_Cu.gbr, KiCAD_uPicomac3_2-B_Fab.gbr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]
2025-05-21 v3.2 of PCB. Updated BOM
    [pmn_v3_2_bom.csv]
2025-05-24 Front and rear case 3D files v3.3
    [pmn_front_3_3.stl, pmn_rear_3_3.stl, pmn_reset_3_2.stl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]
2025-05-24 Removed old version 3.2 folder
    [pmn_front_3_2.stl, pmn_rear_3_2.stl, pmn_reset_3_2.stl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]
2025-05-24 Update README.md
    Amended audio pinouts to match v3.2 PCB
2025-08-17 Add my title bar display code and datasheet
    [pmn_front_3_3_fixed.stl, pmn_rear_3_3_fixed_mixer_fixed.stl, pmn_reset_3_2_fixed.stl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]
2025-08-20 Add RGB HID status and 3d model
    [uPicoMac v16 button_fixed.stl, uPicoMac v16 front_fixed.stl, uPicoMac v16 rear_fixed.stl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]
2025-08-23 works on daxian
    [uPicoMacTypeA v5-button_fixed.stl, uPicoMacTypeA v5-front_fixed.stl, uPicoMacTypeA v5-rear_fixed.stl]

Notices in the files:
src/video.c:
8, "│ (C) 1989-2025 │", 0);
